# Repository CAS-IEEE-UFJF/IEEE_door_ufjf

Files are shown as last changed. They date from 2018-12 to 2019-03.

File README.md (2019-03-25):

<!-- ![](https://img.shields.io/badge/build-passing-rgb(76%2C198%2C31).svg) -->

| Projeto | estado| Observação |
| --- | ----- | --- |
| Leitura e separação entre carterinhas cadastradas e não cadastradas | | -- |
| Modo reunião |  | -- |
| Upload Firebase |  | Problemas na internet do ramo |
| Page local | | -- |
| Page na internet |  | --|

[comment]: <https://img.shields.io/badge/build-unknown-lightgrey.svg>

### [Página online:](https://cas-ieee-ufjf.github.io/IEEE_door_ufjf/)
https://cas-ieee-ufjf.github.io/IEEE_door_ufjf/ é o mesmo site do QR code que está no ramo.

## [ 2º Versão](https://github.com/wesley-cantarino/IEEE_door_ufjf/tree/master/version2)
### Apresentação

O Ramo Estudantil IEEE devido ao seu grande número de membros, necessitava de um melhor controle de acesso ao seu domínio. Porém, as trancas convencionais demandam cópias de chave e não havia como saber quem entrou e em qual horário. A partir disso fizemos um levantamento de qual seria a melhor proposta para resolver o controle de acesso ao tempo que pudéssemos gerenciar as chaves. Em nosso levantamento descobrimos que as carteirinhas estudantis possuíam um dispositivo interno para identificação chamado de radiofrequência chamado RFID, elas por sua vez, são chaves únicas e podem ser obtidas através de leitura.

### Objetivo

O projeto Porta Tunada 2.0 consiste em um equipamento eficiente e de baixo custo para controlar a entrada e saída de pessoas na sala do Ramo Estudantil IEEE UFJF, estando restrito o acesso somente aos membros que tenham suas carteirinhas estudantis cadastradas. Nessa 2º versão fomentamos a equipe o uso do nodeMCU (ESP8266) e para desenvolver a capacidade de programação em IOT.

### Descrição do funcionamento:

Quando uma pessoa aproxima sua carteirinha do equipamento, o RFID - RC522 é o sensor que faz a leitura da tag da carteirinha aproximada. O ESP8266 recebe essa informação e permite que o motor abra a porta, somente se, a mesma for reconhecida. E, então, o LED verde acende e o motor é acionado abrindo a porta. Caso contrário, o buzzer emite um som e o LED vermelho acende. A fonte é utilizada para alimentar o circuito, a ponte H controla o movimento do motor e os jumpers fazem a ligação entre os componentes.

### Componentes utilizados:

* Fonte de 12V;
* Fonte 5V;
* Microcontrolador ESP8266;
* Sensor RFDI - RC522;
* Ponte H - l290n;
* Motor DC;
* Dois LED’s (um vermelho e um verde);
* Buzzer;
* Jumpers.

<hr>

* #### foto:
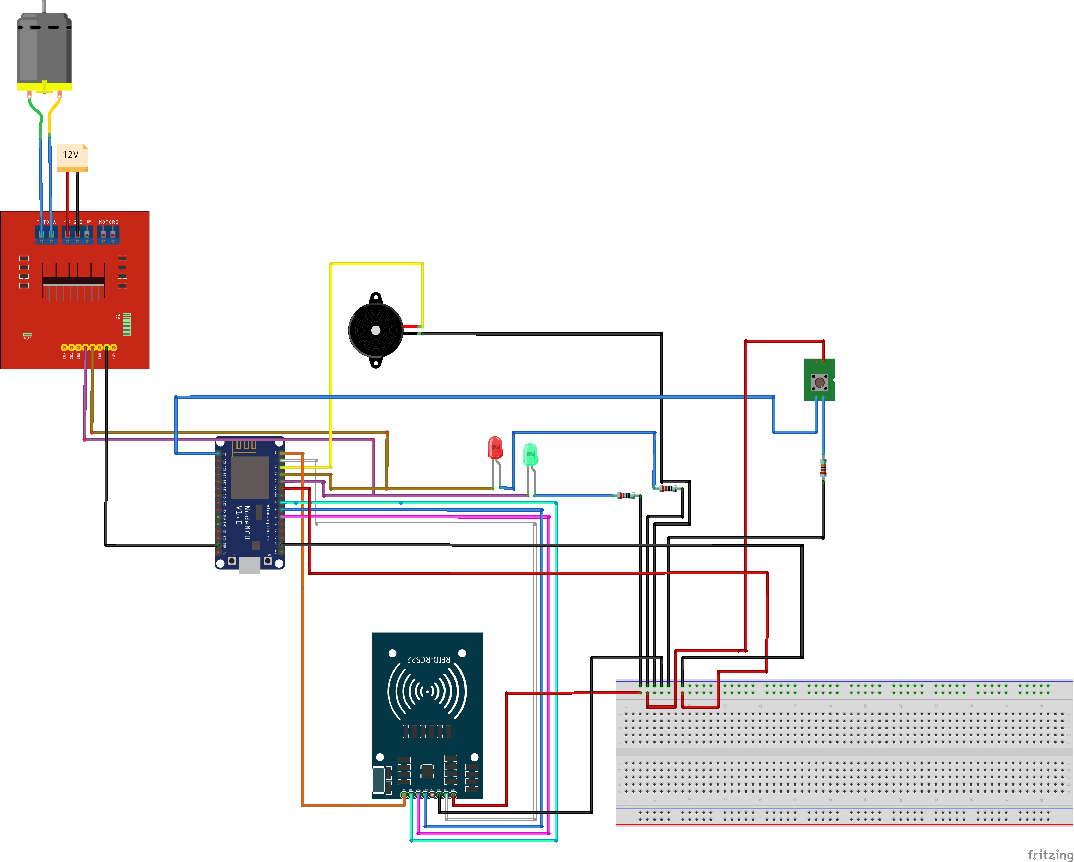
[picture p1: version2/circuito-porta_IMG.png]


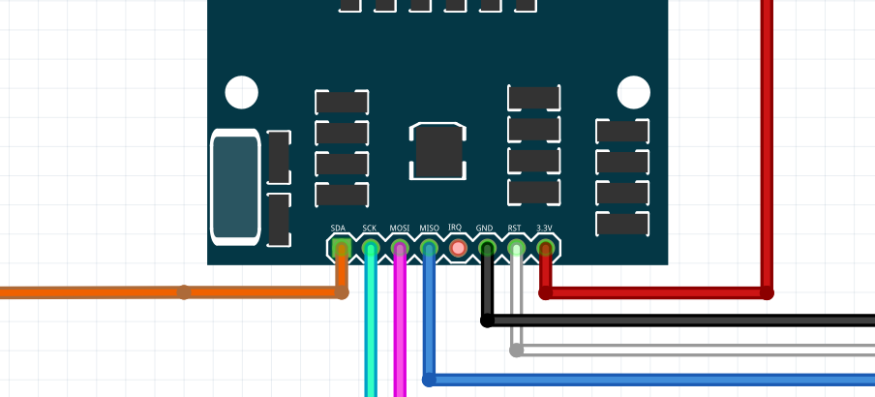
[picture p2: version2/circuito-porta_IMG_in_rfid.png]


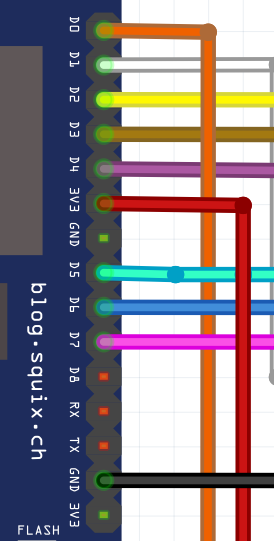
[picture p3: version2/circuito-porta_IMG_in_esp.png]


* #### flowchart:

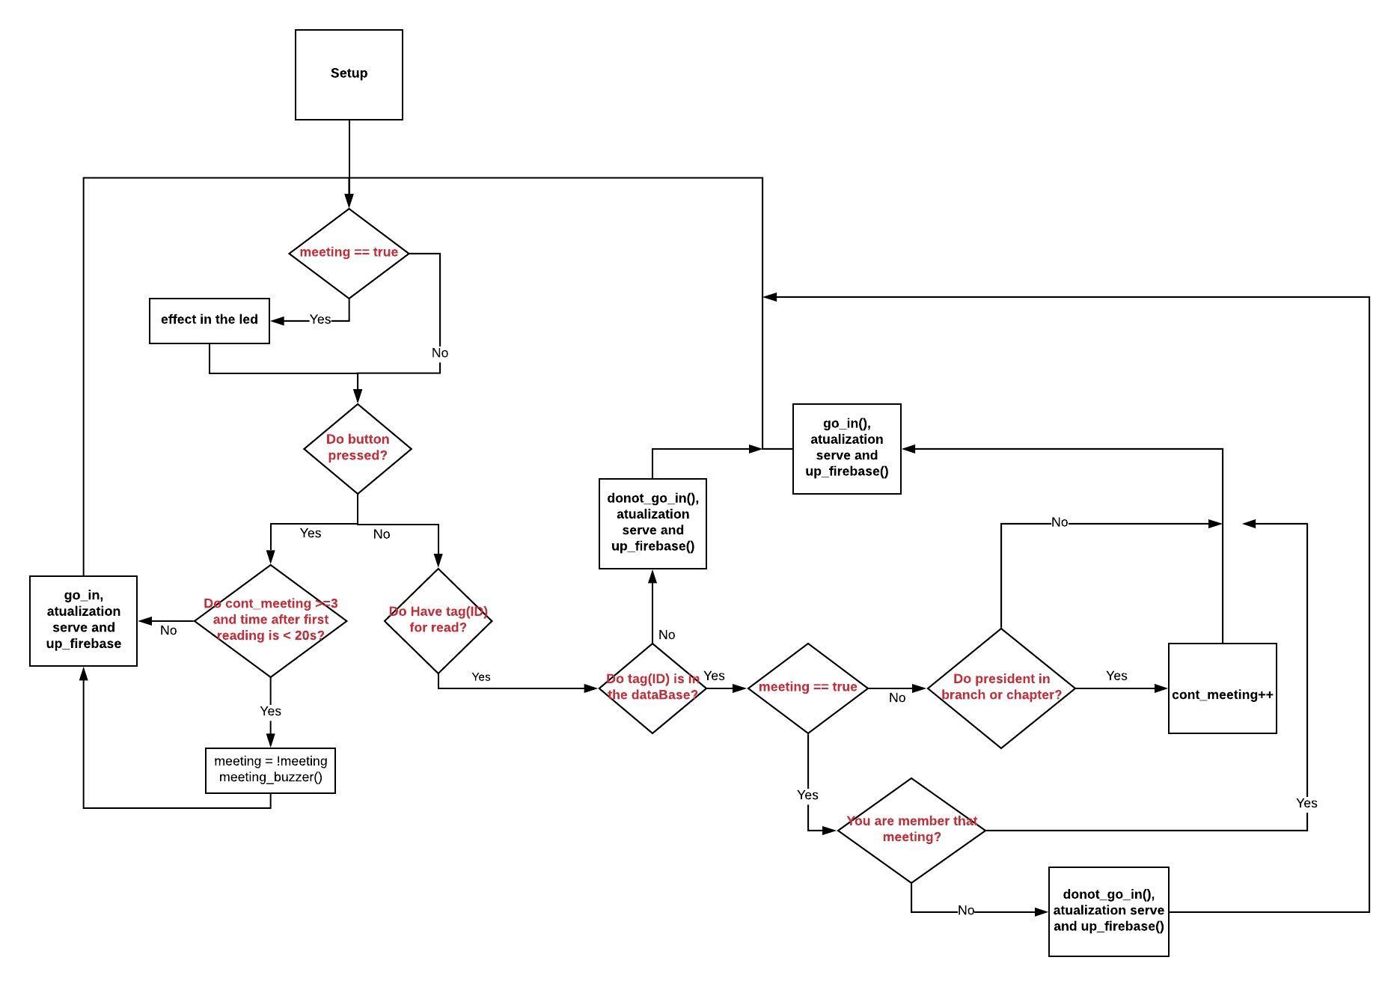
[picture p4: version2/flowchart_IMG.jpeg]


### Oque é modo reunião?

Modo reunião é uma função que permite selecionar quem vai ter acesso ao ramo em determinado momento. Somente o presidente do capítulo ou cargo algum cargo da gestão pode iniciar o modo reunião. 

Exemplo o presidente da eletrônica iniciou o modo reunião. Os led's vão começar a piscar (indicativo que está no modo reunião) e terá efeito sonoro para indicar que estrou no modo reunião. Depois disso, somente membros da eletrônica conseguirão entrar e qualquer outro membro ou presidente terá acesso negado.

Para ativar o modo reunião o presidente terá que passar sua carteirinha 3 ou mais vezes e pressionar o botão interno. Tudo isso em menos de 25s (da para fazer tudo isso em 9s).

Se um presidente passa sua carteirinha, mas não ativa o modo reunião e em menos de 25s vem outro presidente e passa sua carteirinha tentando ativar o modo reunião. Então, esse presidente terá que aguardar o contador interno zerar. Isso leva entorno de 25s.

### Files

```
.
|--- item_adicionais
     |--- contador
          |--- contador.ino
          |--- esquematico_IMG.jpg
          |--- esquematico_fritzing.fzz
          |--- sn74hc595-datasheet.pdf
          |--- video_01.mp4
          |--- video_02.mp4
     |--- matriz_numerica
          |--- library
               |--- keypad.zip
          |--- ZRX_543.jpg
          |--- matriz_numerica.ino
     |--- readme.md
|--- version1
     |--- main.ino
|--- version2
     |--- CODE
          |--- library
               |--- firebase-arduino-master.rar
               |--- rfid-master.rar
          |--- testes
               |--- test_RFID_only.ino
               |--- test_simples.ino
               |--- textHTML_exemple.html
          |--- main.ino
     |--- circuito-porta.fzz
     |--- circuito-porta_IMG.png
     |--- circuito-porta_IMG_in_esp.png
     |--- circuito-porta_IMG_in_rfid.png
     |--- componentes.txt
     |--- flowchart_IMG.jpeg
|--- .gitignore
|--- README.md
|--- this_is_nodeMCU.pdf
```

## [ 1º Versão](https://github.com/wesley-cantarino/IEEE_door_ufjf/tree/master/version1)
Objetivo da 1º versão é apresentar para a equipe o Arduino e desenvolver a capacidade de programação.

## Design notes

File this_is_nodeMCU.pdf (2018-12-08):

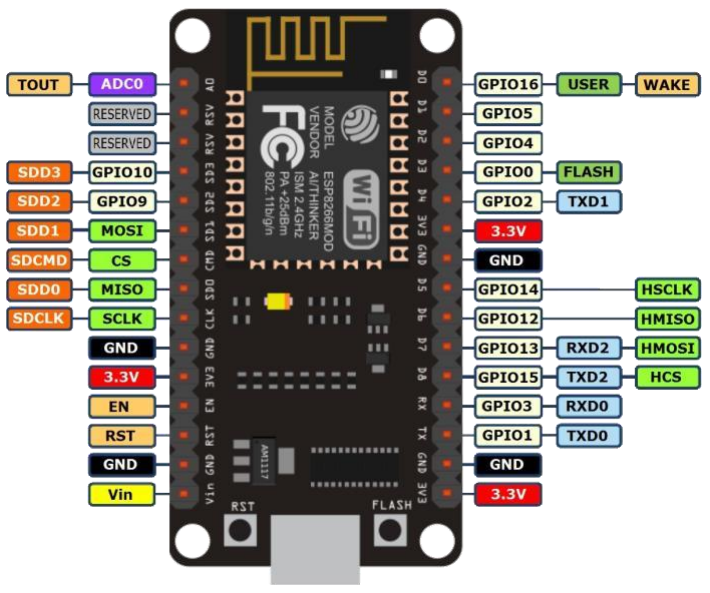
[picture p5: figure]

- VIN – Esse é o pino de alimentação externa ( recomendo 5,0V / 1A). Pode usar até 9V, mas o regulador da placa deverá esquentar. Não use-o se estiver usando a USB.
- GND– Esse é o terra da placa. Não se esqueça de conectá-lo ao terra de outros dispositivos.
- RST – Reset do módulo ESP-12. Nível LOW(0V) dá um reboot na placa.
- EN – (Enable) ativa o módulo ESP-12 quando o nível for HIGH(3,3V).
- 3.3V – saída do regulador interno 3,3V – Para alimentar outro dispositivo, não use mais do que 500 mA de corrente.
- CLK – interface SPI (clock) – pino SCLK (GPIO_6)

- SD0 – interface SPI (master in serial out) – pino MISO (GPIO_7)
- CMD – interface SPI (chip select) – pino CS (GPIO_11)
- SD1 – interface SPI (master out serial in) – pino MOSI (GPIO_8)
- SD2 – pino GPIO_9 pode ser usado também para comunicação com SD Card (SDD2)
- SD3 – pino GIPO_10 – pode ser usado também para comunicação com SD Card (SDD3)
- RSV – reservado (não use).
- ADC0– pino de entrada do conversor analógico digital ADC de 10 bits. Tensão máxima de 1,1V (variação do valor digital – 0 a 1024).

D0 – pino GIPO_16 pode ser usado para acordar (WAKE UP) o ESP8266 em modo sono profundo (Deep sleep mode).

D1 – pino GPIO_5 – entrada ou saída.

D2 – pino GIPO_4 – entrada ou saída.

D3 – pino GPIO_0 é usado também para controlar o upload do programa na memória Flash. Esta conectado no botão FLASH.

D4 – pino GPIO_2 – UART_TXD1 quando carregando o programa na memória FLASH

D5 – pino GPIO_14 pode ser usado em SPI de alta velocidade (HSPI-SCLK)

D6 – pino GPIO_12 pode ser usado em SPI de alta velocidade (HSPI-MISO)

D7 – pino GPIO_13 pode ser usado em SPI de alta velocidade (HSPI-MOSI) ou UART0_CTS.

D8 – pino GPIO_15 pode ser usado em SPI de alta velocidade (HSPI-CS) ou UART0_RTS.

RX – pino GPIO_3 – U0RXD quando carregando o programa na memória FLASH.

TX – pino GIPO_1 – U0TXD quando carregando o programa na memória FLASH.

GPIO
static const uint8_t D0 | = 16;
static const uint8_t D1 | = 5;
static const uint8_t D2 | = 4;
static const uint8_t D3 | = 0;
static const uint8_t D4 | = 2;
static const uint8_t D5 | = 14;
static const uint8_t D6 | = 12;
static const uint8_t D7 | = 13;
static const uint8_t D8 | = 15;
static const uint8_t D9 | = 3;
static const uint8_t D10 | = 1;

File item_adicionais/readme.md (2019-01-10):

### What's contador?

  Contador é um CI que permite realizar a escrita digital de até 8 portas usando apenas 3 portas do seu microcontrolador.

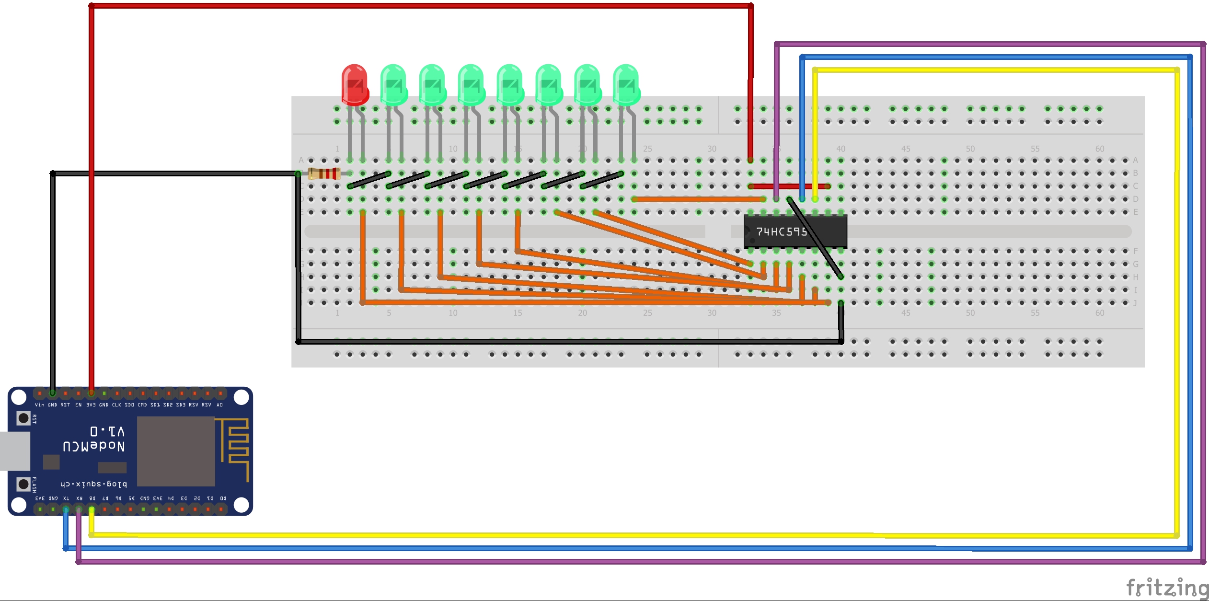
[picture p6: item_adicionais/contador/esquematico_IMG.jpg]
  

### What's matriz numérica?

  É uma tabela de 16 botões com números indo de 0 a F (hexadecimais).

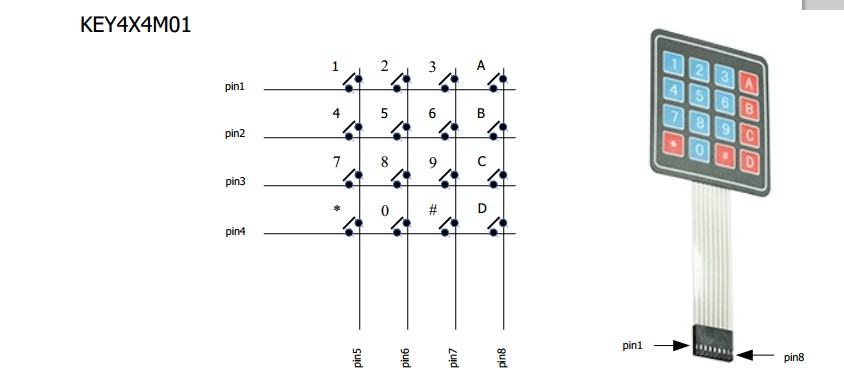
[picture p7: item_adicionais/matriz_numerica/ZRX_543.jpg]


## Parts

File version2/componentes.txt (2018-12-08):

Fonte 12V_____ R$ 15
       5V_____ R$ ??

ESP8266_______ R$ 35
RFID__________ R$ 15
Ponte H l290n_ R$ 18
Motor_________ R$ 20

LED (x2)____  
Buzzer______ 
jumper (xN)_

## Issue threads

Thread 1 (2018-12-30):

collapse RFID

wesley-cantarino, 2018-12-30:
_From @wesley-cantarino on December 18, 2018 23:47_

#### Apos certo tempo (indeterminado) o RFID para de responder

Lendo o readme da biblioteca descobri esses 4 tópicos:

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

_Copied from original issue: wesley-cantarino/IEEE_door_ufjf#1_

wesley-cantarino, 2019-01-06:
Quando tempo algum corpo entre ou próximo da tag e do rfid.

Exemplo o rfid em cima do notebook (metal).

O rfid NÂO faz leitura da tag. talvez, se colocar uma esponja atrás do rfid ajude.

wesley-cantarino, 2019-01-06:
07/01 vou soldar os pinos SPI  e vou adicionar essas linhas dentro da função loop

``` C++
rfid.PCD_Init();
rfid.PCD_SetAntennaGain(rfid.RxGain_max);
delay(500);
```

tomara que isto funcione

wesley-cantarino, 2019-01-08:
por enquanto está tudo tranquilo 😄

Closed 2019-03-07.

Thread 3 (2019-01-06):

Outros artigos :smile:

wesley-cantarino, 2019-01-06:
add pdf here

wesley-cantarino, 2019-01-06:
muito bom este PDF [rfidmifare.pdf](https://github.com/CAS-IEEE-UFJF/IEEE_door_ufjf/files/2730045/rfidmifare.pdf)

muito bom este site https://blogventor.wordpress.com/2017/04/14/how-does-rfid-communicate-with-arduino/

wesley-cantarino, 2019-01-10:
programação orientada a objeto com arduino

https://www.radishlogic.com/arduino/use-c-class-arduino-ide-without-creating-library/

https://www.geeksforgeeks.org/array-class-c/

wesley-cantarino, 2019-01-10:
http://people.cs.vt.edu/kafura/cs2704/arrays.html

wesley-cantarino, 2019-01-11:
```C++
const int c = 261;
const int d = 294;
const int e = 329;
const int f = 349;
const int g = 391;
const int gS = 415;
const int a = 440;
const int aS = 455;
const int b = 466;
const int cH = 523;
const int cSH = 554;
const int dH = 587;
const int dSH = 622;
const int eH = 659;
const int fH = 698;
const int fSH = 740;
const int gH = 784;
const int gSH = 830;
const int aH = 880;

#define buzzerPin D2
const int ledPin1 = 12;
const int ledPin2 = 13;

int counter = 0;

void setup()
{
  //Setup pin modes
  pinMode(buzzerPin, OUTPUT);
  pinMode(ledPin1, OUTPUT);
  pinMode(ledPin2, OUTPUT);
}

void loop()
{

  //Play first section
  firstSection();

  //Play second section
  secondSection();

  //Variant 1
  beep(f, 250);
  beep(gS, 500);
  beep(f, 350);
  beep(a, 125);
  beep(cH, 500);
  beep(a, 375);
  beep(cH, 125);
  beep(eH, 650);

  delay(500);

  //Repeat second section
  secondSection();

  //Variant 2
  beep(f, 250);
  beep(gS, 500);
  beep(f, 375);
  beep(cH, 125);
  beep(a, 500);
  beep(f, 375);
  beep(cH, 125);
  beep(a, 650);

  delay(650);
}

void beep(int note, int duration)
{
  //Play tone on buzzerPin
  tone(buzzerPin, note, duration);

  //Play different LED depending on value of 'counter'
  if(counter % 2 == 0)
  {
    digitalWrite(ledPin1, HIGH);
    delay(duration);
    digitalWrite(ledPin1, LOW);
  }else
  {
    digitalWrite(ledPin2, HIGH);
    delay(duration);
    digitalWrite(ledPin2, LOW);
  }

  //Stop tone on buzzerPin
  noTone(buzzerPin);

  delay(50);

  //Increment counter
  counter++;
}

void firstSection()
{
  beep(a, 500);
  beep(a, 500);
  beep(a, 500);
  beep(f, 350);
  beep(cH, 150);
  beep(a, 500);
  beep(f, 350);
  beep(cH, 150);
  beep(a, 650);

  delay(500);

  beep(eH, 500);
  beep(eH, 500);
  beep(eH, 500);
  beep(fH, 350);
  beep(cH, 150);
  beep(gS, 500);
  beep(f, 350);
  beep(cH, 150);
  beep(a, 650);

  delay(500);
}

void secondSection()
{
  beep(aH, 500);
  beep(a, 300);
  beep(a, 150);
  beep(aH, 500);
  beep(gSH, 325);
  beep(gH, 175);
  beep(fSH, 125);
  beep(fH, 125);
  beep(fSH, 250);

  delay(325);

  beep(aS, 250);
  beep(dSH, 500);
  beep(dH, 325);
  beep(cSH, 175);
  beep(cH, 125);
  beep(b, 125);
  beep(cH, 250);

  delay(350);
}
```

wesley-cantarino, 2019-01-23:
### Database as a Service with Firebase

https://www.youtube.com/watch?v=JrHT1iqSrAQ&list=PLRqwX-V7Uu6agS82Le9lLCBbeaW8inATT

wesley-cantarino, 2019-01-23:
### Working with data

https://www.youtube.com/watch?v=rJaXOFfwGVw&list=PLRqwX-V7Uu6a-SQiI4RtIwuOrLJGnel0r

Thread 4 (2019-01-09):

fotos

wesley-cantarino, 2019-01-09:
fotos do projeto e memes :D

wesley-cantarino, 2019-01-09:
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

wesley-cantarino, 2019-01-09:
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

wesley-cantarino, 2019-01-09:
[videos_ate_09_01_2019_que_eu_tenho.zip](https://github.com/CAS-IEEE-UFJF/IEEE_door_ufjf/files/2740444/videos_ate_09_01_2019_que_eu_tenho.zip)

wesley-cantarino, 2019-01-12:
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
[videos_11_01_2019.zip](https://github.com/CAS-IEEE-UFJF/IEEE_door_ufjf/files/2751540/videos_11_01_2019.zip)

wesley-cantarino, 2019-01-25:
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

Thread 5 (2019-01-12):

fazer som com buzzer

wesley-cantarino, 2019-01-12:

wesley-cantarino, 2019-01-12:
star wars

```C++
const int c = 261;
const int d = 294;
const int e = 329;
const int f = 349;
const int g = 391;
const int gS = 415;
const int a = 440;
const int aS = 455;
const int b = 466;
const int cH = 523;
const int cSH = 554;
const int dH = 587;
const int dSH = 622;
const int eH = 659;
const int fH = 698;
const int fSH = 740;
const int gH = 784;
const int gSH = 830;
const int aH = 880;

const int buzzerPin = 8;
const int ledPin1 = 12;
const int ledPin2 = 13;

int counter = 0;

void setup()
{
  //Setup pin modes
  pinMode(buzzerPin, OUTPUT);
  pinMode(ledPin1, OUTPUT);
  pinMode(ledPin2, OUTPUT);
}

void loop()
{

  //Play first section
  firstSection();

  //Play second section
  secondSection();

  //Variant 1
  beep(f, 250);
  beep(gS, 500);
  beep(f, 350);
  beep(a, 125);
  beep(cH, 500);
  beep(a, 375);
  beep(cH, 125);
  beep(eH, 650);

  delay(500);

  //Repeat second section
  secondSection();

  //Variant 2
  beep(f, 250);
  beep(gS, 500);
  beep(f, 375);
  beep(cH, 125);
  beep(a, 500);
  beep(f, 375);
  beep(cH, 125);
  beep(a, 650);

  delay(650);
}

void beep(int note, int duration)
{
  //Play tone on buzzerPin
  tone(buzzerPin, note, duration);

  //Play different LED depending on value of 'counter'
  if(counter % 2 == 0)
  {
    digitalWrite(ledPin1, HIGH);
    delay(duration);
    digitalWrite(ledPin1, LOW);
  }else
  {
    digitalWrite(ledPin2, HIGH);
    delay(duration);
    digitalWrite(ledPin2, LOW);
  }

  //Stop tone on buzzerPin
  noTone(buzzerPin);

  delay(50);

  //Increment counter
  counter++;
}

void firstSection()
{
  beep(a, 500);
  beep(a, 500);
  beep(a, 500);
  beep(f, 350);
  beep(cH, 150);
  beep(a, 500);
  beep(f, 350);
  beep(cH, 150);
  beep(a, 650);

  delay(500);

  beep(eH, 500);
  beep(eH, 500);
  beep(eH, 500);
  beep(fH, 350);
  beep(cH, 150);
  beep(gS, 500);
  beep(f, 350);
  beep(cH, 150);
  beep(a, 650);

  delay(500);
}

void secondSection()
{
  beep(aH, 500);
  beep(a, 300);
  beep(a, 150);
  beep(aH, 500);
  beep(gSH, 325);
  beep(gH, 175);
  beep(fSH, 125);
  beep(fH, 125);
  beep(fSH, 250);

  delay(325);

  beep(aS, 250);
  beep(dSH, 500);
  beep(dH, 325);
  beep(cSH, 175);
  beep(cH, 125);
  beep(b, 125);
  beep(cH, 250);

  delay(350);
}
```

wesley-cantarino, 2019-01-12:
donot_go_in

```C++
tone(BUZZER, 523);
  delay(180);
  noTone(BUZZER);

  tone(BUZZER, 294);
  delay(120);
  noTone(BUZZER);

  tone(BUZZER, 440);
  delay(110);
  noTone(BUZZER);

  tone(BUZZER, 349);
  delay(110);
  noTone(BUZZER);

  tone(BUZZER, 294);
  delay(100);
noTone(BUZZER);
```

wesley-cantarino, 2019-01-12:
go_in_DEV

```C++
 tone(BUZZER, 294);
  delay(100);
  noTone(BUZZER);

  tone(BUZZER, 349);
  delay(110);
  noTone(BUZZER);

  tone(BUZZER, 440);
  delay(110);
  noTone(BUZZER);

  tone(BUZZER, 294);
  delay(120);
  noTone(BUZZER);

  tone(BUZZER, 523);
  delay(180);
  noTone(BUZZER);

  delay(100);
  tone(BUZZER, 523);
  delay(180);
noTone(BUZZER);
```

wesley-cantarino, 2019-01-12:
go_in
```C++
tone(BUZZER, 294);
  delay(100);
  noTone(BUZZER);

  tone(BUZZER, 349);
  delay(110);
  noTone(BUZZER);

  tone(BUZZER, 440);
  delay(110);
  noTone(BUZZER);

  tone(BUZZER, 294);
  delay(120);
  noTone(BUZZER);

  tone(BUZZER, 523);
  delay(180);
noTone(BUZZER);
```

Closed 2019-03-07.

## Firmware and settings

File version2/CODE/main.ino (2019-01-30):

/*************************************************************************************************/
/* ÚLTIMA:     ATUALIZAÇÃO                                           UPLOAD nodeMCU              */
/*           30/01/2019 11:00                                       30/01/2019 12:00             */
/*                                                                                               */
/*     30/01/2019 11:00 - Ajuster na função main                                                 */
/*     27/01/2019 12:00 - Novos comentários                                                      */
/*     26/01/2019 14:21 - Correção do Modo reunião, print_DEV enviando t == true e f == false,   */
/*set tempo máximo de reunião como 1h20 == 80min.                                                */
/*     25/01/2019 17:00 - Retornar para versão de segunda feira (21/01/2019) pois ela esta       */
/*estável.                                                                                       */
/*************************************************************************************************/

/*************************************************************************************************/
/*                                  NOTAS sobre modo reunião                                     */
/* Ex: Eu (wesley) passo minha minha carteirinha 2 vezes seguidas (exemplo) mas eu não ativo o   */
/*modo reunião (eu não quero ativar modo reunião) e digamos que o próximo  pessoa seja um        */
/*presidente e queira ativar modo reunião. Ele NÃO vai conseguir pois o contador está vinculada a*/
/*minha carteirinha somente após 25s depois da minha primeira leitura que ele vai conseguir      */
/*ativar o modo reunião.                                                                         */
/*                                                                                               */
/*                                        BUTTON                                                 */
/* O tempo de resposta do botão NÂO está instantâneo!!!!!! para resolver isso, teríamos que usar */
/*interrupção por hardware e eliminar os delay(). É melhor educar a galera como sendo um botão de*/
/*pressão                                                                                        */
/*************************************************************************************************/

/*****library_str******/ //str == start
#include <Arduino.h> //tem que importar pois estou usando platformIO

//na real mesmo tem biblioteca aqui que não esta sendo usada mas deixa assim mesmo
#include <ESP8266WiFi.h>
#include <WiFiClient.h>
#include <ESP8266WebServer.h>
#include <ESP8266mDNS.h>
#include <DNSServer.h>
#include <ESP8266HTTPClient.h>

#include <FirebaseArduino.h> //o biblioteca problematica. só de importar já da erro

#include <SPI.h> //protocol SPI
#include <MFRC522.h> //RFID
/*****library_end******/

/************************/
#define RST_PIN 5  //GPIO05 ou D1 no nodeMCU, Reset no RFID
#define SS_PIN 16  //GPIO15 ou D0 no nodeMCU, SDA no RFID
                   //GPIO12 ou D6 no nodeMCU, MISO no RFID
                   //GPIO13 ou D7 no nodeMCU, MOSI no RFID
                   //GPIO14 ou D5 no nodeMCU, SCK no RFID

MFRC522 mfrc522(SS_PIN, RST_PIN);

/*os pinos de controle do motor também estão ligados aqui(ou seja a ponte H e os LED vermelho e verde tem na verdade o
mesmo pino) pois não tem 2 pinos sobrando só para eles*/

#define RED_LED D4
#define GRE_LED D3

#define BUZZER  D2

const int button = A0;
/************************/

/************************/
/*
const char* ssid = "";      //nome da rede
const char* password = "";  //senha da rede
*/
const char* ssid = "";      //nome da rede
const char* password = "";  //senha da rede
/*
const char* ssid = "";      //nome da rede
const char* password = "";  //senha da rede
*/

#define FIREBASE_HOST ""   //autenticação no firebase
#define FIREBASE_AUTH ""

ESP8266WebServer server(80);  //porta 80 é padrão para entrada e saída de dados
/************************/

/************************/
class membro_class
{
  public:
    String UID, nome;
    boolean dev = false; //grupos em que a pessoa está. Por padrão vem setado como falso

    bool coisas [27] = {false};
    /*Conseguem iniciar modo reunião
       0   false, //CAS: presidente
       1   false, //RAS: presidente
       2   false, //PES: presidente
       3   false, //IAS: presidente
       4   false, //SIGHT: presidente
       5   false, //WIE: presidente
       6   false, //SPEAK: presidente
       7   false, //QUALIDADE: presidente
       8   false, //MKT: presidente
       9   false, //EVENTOS: presidente
       10  false, //TI: presidente
       11  false, //CONSELHO: presidente
       12  false, //GP: presidente
       13  false, //PROFESSOR: presidente

	  NÃO conseguem iniciar modo reunião
       14  false, //CAS: membro
       15  false, //RAS: membro
       16  false, //PES: membro
       17  false, //IAS: membro
       18  false, //SIGHT: membro
       19  false, //WIE: membro
       20  false, //SPEAK: membro
       21  false, //QUALIDADE: membro
       22  false, //MKT: membro
       23  false, //EVENTOS: membro
       24  false, //TI: membro
       25  false, //CONSELHO: membro
       26  false, //GP: membro

       27 no total
    */

    membro_class(String UID_aux, String nome_aux)
    {
      UID = UID_aux;
      nome = nome_aux;
    }
};

int tam_DB = 25; //tam db //<---------- alterar aqui!!!!!!!
membro_class membro[] =
{
    
};

boolean print_DEV = false; //imprimir variáveis na porta USB

String tag_now = "";  //tag lida recentimente
int tag_db = 0;

//histórico no servidor local
String tag_backup[32] = ""; //código da tag
int tag_db_backup[32];      //posição da tag
int tag_y_db_backup[32];    //está no db?

boolean meeting = false; //modo reunião
int cont_meeting = 0; //contador para reunião

int quem_ativou = 200;

String tag_time = ""; //tag quando o contador (cont_meeting) é 1
double time_now = 0;
double time_aux = 0;
double time_max = 0;
//tem var aqui que podem se descartadas... mas... code 100% otimizado, não é prioridade.

void oque_a_pessoa_faz ()
{ //se a pessoa é desenvolvedor...
  //encontrar a pessoa e colocar verdadeiro(true) nas coisas que ela faz


}
/************************/

/*******server_str*******/
void handleRoot ()
{//html mega complexo...hahaha
  String textHTML;

  textHTML += "<!DOCTYPE HTML>";
  textHTML += "<html>";
    textHTML += "<head>";
      textHTML += " <meta http-equiv='refresh' content='3'>";
      textHTML += "<meta name'viewport' content='width=device-width, initial-scale=1.0'>";
      textHTML += "<title>ESP8266 Server</title>";
      textHTML += "<style>";
        textHTML += "body{background-color: #efefef;}";
      textHTML += "</style>";
    textHTML += "</head>";

    textHTML += "<body>";
      textHTML += "<center>";
      textHTML += "<h1>TAG</h1>";

      /************************/
      for(int i = 0; i < 32; i++)
      {
        textHTML += tag_backup[i]; //UID
        textHTML += ", ";

        if(tag_y_db_backup[i] == 1)
        {
        textHTML += membro[tag_db_backup[i]].nome;
        textHTML += "<br>";
        }
        else
        {
          textHTML += "unknown<br>";
        }
      }
      /************************/

    textHTML += "</body>";
  textHTML += "</html>";

  server.send(200, "text/html", textHTML);
}

void handleNotFound ()
{
  String message = "File Not Found\n\n";
  message += "URI: ";
  message += server.uri();
  message += "\nMethod: ";
  message += (server.method() == HTTP_GET)?"GET":"POST";
  message += "\nArguments: ";
  message += server.args();
  message += "\n";
  for (uint8_t i=0; i<server.args(); i++)
  {
    message += " " + server.argName(i) + ": " + server.arg(i) + "\n";
  }
  server.send(404, "text/plain", message);
}
/*******server_end*******/

void go_in ()
{ //efeito normal de entrada (go_in)
  if(print_DEV)
    Serial.println("go_in V");

  digitalWrite(GRE_LED, HIGH);
  digitalWrite(RED_LED, LOW);
  /*************************/

  tone(BUZZER, 294);
  delay(100);
  noTone(BUZZER);

  tone(BUZZER, 349);
  delay(110);
  noTone(BUZZER);

  tone(BUZZER, 440);
  delay(110);
  noTone(BUZZER);

  tone(BUZZER, 294);
  delay(120);
  noTone(BUZZER);

  tone(BUZZER, 523);
  delay(180);
  noTone(BUZZER);

  /*************************/
  delay(500); //delay here
  digitalWrite(GRE_LED, LOW);
  digitalWrite(RED_LED, LOW);

  delay(50);
  digitalWrite(GRE_LED, LOW);
  digitalWrite(RED_LED, HIGH);
  delay(100);
  digitalWrite(GRE_LED, LOW);
  digitalWrite(RED_LED, LOW);
}

void go_in_DEV ()
{ //efeito diferenciado de entrada (go_in_DEV) para developer
  if(print_DEV)
    Serial.println("go_in_DEV V");

  digitalWrite(GRE_LED, HIGH);
  digitalWrite(RED_LED, LOW);
  /*************************/

  tone(BUZZER, 294);
  delay(100);
  noTone(BUZZER);

  tone(BUZZER, 349);
  delay(110);
  noTone(BUZZER);

  tone(BUZZER, 440);
  delay(110);
  noTone(BUZZER);

  tone(BUZZER, 294);
  delay(120);
  noTone(BUZZER);

  tone(BUZZER, 523);
  delay(180);
  noTone(BUZZER);

  delay(100);
  tone(BUZZER, 523);
  delay(180);
  noTone(BUZZER);

  /*************************/
  delay(500); //delay here
  digitalWrite(GRE_LED, LOW);
  digitalWrite(RED_LED, LOW);

  digitalWrite(GRE_LED, LOW);
  digitalWrite(RED_LED, HIGH);
  delay(100);
  digitalWrite(GRE_LED, LOW);
  digitalWrite(RED_LED, LOW);

  if(print_DEV)
    Serial.println("developer");
}


/******************************/
//minha música de star wars hehe
const int c = 261;
const int d = 294;
const int e = 329;
const int f = 349;
const int g = 391;
const int gS = 415;
const int a = 440;
const int aS = 455;
const int b = 466;
const int cH = 523;
const int cSH = 554;
const int dH = 587;
const int dSH = 622;
const int eH = 659;
const int fH = 698;
const int fSH = 740;
const int gH = 784;
const int gSH = 830;
const int aH = 880;

int counter = 0;

void beep(int note, int duration)
{
  //Play tone on buzzerPin
  tone(BUZZER, note);
  delay(duration);

  //Stop tone on buzzerPin
  noTone(BUZZER);

  delay(50);

  //Increment counter
  counter++;
}

void firstSection()
{
  beep(a, 500);
  beep(a, 500);
  beep(a, 500);
  beep(f, 350);
  beep(cH, 150);
  beep(a, 500);
  beep(f, 350);
  beep(cH, 150);
  beep(a, 650);

  /*
  delay(500);

  beep(eH, 500);
  beep(eH, 500);
  beep(eH, 500);
  beep(fH, 350);
  beep(cH, 150);
  beep(gS, 500);
  beep(f, 350);
  beep(cH, 150);
  beep(a, 650);

  delay(500);
  */
}

void secondSection()
{
  beep(aH, 500);
  beep(a, 300);
  beep(a, 150);
  beep(aH, 500);
  beep(gSH, 325);
  beep(gH, 175);
  beep(fSH, 125);
  beep(fH, 125);
  beep(fSH, 250);

  delay(325);

  beep(aS, 250);
  beep(dSH, 500);
  beep(dH, 325);
  beep(cSH, 175);
  beep(cH, 125);
  beep(b, 125);
  beep(cH, 250);

  delay(350);
}

void go_in_DEV_star_wars ()
{
  if(print_DEV)
    Serial.println("go_in_DEV_star_wars V");

  digitalWrite(GRE_LED, HIGH);
  digitalWrite(RED_LED, LOW);
  /*************************/

  //Play first section
  firstSection();

  //Play second section
  //secondSection();

  /*************************/
  digitalWrite(GRE_LED, LOW);
  digitalWrite(RED_LED, LOW);

  digitalWrite(GRE_LED, LOW);
  digitalWrite(RED_LED, HIGH);
  delay(100);
  digitalWrite(GRE_LED, LOW);
  digitalWrite(RED_LED, LOW);

  if(print_DEV)
    Serial.println("developer");
}
/******************************/

void donot_go_in ()
{ //tag nao cadastrada
  if(print_DEV)
    Serial.println("donot_go_in V");

  digitalWrite(RED_LED, HIGH);

  tone(BUZZER, 523);
  delay(180);
  noTone(BUZZER);

  tone(BUZZER, 294);
  delay(120);
  noTone(BUZZER);

  tone(BUZZER, 440);
  delay(110);
  noTone(BUZZER);

  tone(BUZZER, 349);
  delay(110);
  noTone(BUZZER);

  tone(BUZZER, 294);
  delay(100);
  noTone(BUZZER);

  digitalWrite(RED_LED, LOW);
}

void meeting_led ()
{ //piscar led vermelho para indicar que está em reunião
  digitalWrite(RED_LED, HIGH);
  digitalWrite(GRE_LED, HIGH);
  delay(200);
  digitalWrite(RED_LED, LOW);
  digitalWrite(GRE_LED, LOW);
  delay(100);
}

void meeting_buzzer ()
{
  tone(BUZZER, 294);
  delay(120);
  noTone(BUZZER);

  tone(BUZZER, 440);
  delay(110);
  noTone(BUZZER);
}

void up_firebase (String tag, boolean go_db)
{ //enviar as tag para firebase
  //desativado pois o roteador próprio do ramo não está conectando a internet
  /*
  if(print_DEV)
    Serial.println("-------firebase str-----------");

  if(go_db)
    Firebase.pushString("tag_read", tag + ", "); //+ name); falta o nome da pessoa
  else
    Firebase.pushString("tag_read", tag + ", " + "unknown");

  if (Firebase.failed())
  {
    if(print_DEV)
    {
      Serial.print("setting /number failed:");
      Serial.println(Firebase.error());
    }
  }

  if(print_DEV)
  {
    Serial.print("firebase: tag now: ");
    Serial.println(tag);
    Serial.println("--------firebase end----------");
  }*/
}

void function_main_meeting ()
{
  boolean go = false; //var aux para seber se a tag esta no db

  if(print_DEV)
    Serial.println("modo reuniao");

  for (int ddb = 0; ddb < tam_DB; ddb++)
  {//varrer db
    if (membro[ddb].UID == tag_now)
    {//se tiver no db
      if(print_DEV)
        Serial.println("Yes db");

        int va = quem_ativou - 14;
        if (membro[ddb].coisas[va])
        {//se for presidente então cont_meeting = cont_meeting + 1
          if(print_DEV)
          {
            Serial.print("presidente: ");
            Serial.println(va);
          }

          if(tag_time == tag_now)
          {
            cont_meeting += 1;

            if(!go)
              go_in();

            go = true;

            if(cont_meeting > 2)
              quem_ativou = va + 14;

            if(print_DEV)
            {
              Serial.print("cont_meeting += 1 --->");
              Serial.println(cont_meeting);
            }
          }

          if(cont_meeting == 0)
          {
            cont_meeting += 1;

            if(!go)
              go_in();

            go = true;
          }

          if(cont_meeting == 1)
          {
            time_now = millis();
            tag_time = tag_now;
          }

          if(print_DEV)
          {
            Serial.print(" va: ");
            Serial.println(va);
          }
        }

      if(!go)
      {
        if (membro[ddb].coisas[quem_ativou])
        {
          if(print_DEV)
          {
            Serial.print("ddb: ");
            Serial.println(ddb);
            Serial.println("-----");

            Serial.print("quem_ativou: ");
            Serial.println(quem_ativou);
          }
          if(!go)
            go_in();

          go = true;
        }
      }
      /*************/
    }
  }

  if(go == false)
  {
    donot_go_in();
  }
  else
  {
    go = false;
  }
}

void function_main_normal ()
{
  boolean go = false; //var aux para seber se a tag esta no db

  for(int i = 0; i < tam_DB; i++)
  {
    if (membro[i].UID == tag_now)
    {
      if(print_DEV)
        Serial.println("Yes db");

      //responsável por preparar o modo reunião
      for(int va = 0; va < 14; va++)
      {//varrer todos os presidentes
        if (membro[i].coisas[va])
        {//se for presidente então cont_meeting = cont_meeting + 1
          if(print_DEV)
          {
            Serial.print("presidente: ");
            Serial.println(va);
          }

          if(tag_time == tag_now)
          {
            cont_meeting += 1;

            if(cont_meeting > 2)
              quem_ativou = va + 14;

            if(print_DEV)
            {
              Serial.print("cont_meeting += 1 --->");
              Serial.println(cont_meeting);
            }
          }

          if(cont_meeting == 0)
          {
            cont_meeting += 1;

            time_now = millis();
            tag_time = tag_now;
          }

          if(print_DEV)
          {
            Serial.print(" va: ");
            Serial.println(va);
          }
        }
      }

      if (membro[i].dev) //eh developer
      {
        if ((membro[i].UID == "FD 3C 50 C5") || //eu quero que minha entrada seja triunfal
            (membro[i].UID == "51 4F E2 08"))
        {
          go_in_DEV_star_wars();
        }
        else
          go_in_DEV();
      }
      else
        go_in();


      tag_db_backup[0] = i;
      go = true;
      tag_y_db_backup[0] = 1;
    }
  }

  if (!go)
  {
    donot_go_in();
    if(print_DEV)
      Serial.println("No db");

    tag_y_db_backup[0] = 0;
  }

  up_firebase(tag_now, go); //envia a tag para firebase
  go = !go;
}

void function_main ()
{
  /*
    * Essa é a função principal pois é daqui que vai ser definido oque fazer com a tag lida
    * Verifica se esta no modo reunião.
    * Verifica se a tag esta no banco de dados. se sim, chama a função go_in ou go_in_DEV se for tag especial(developer)
  */

  for(int i = 31; i > 0; i--)
  {
    tag_backup [i] = tag_backup [i - 1];
    tag_db_backup [i] = tag_db_backup [i - 1];
    tag_y_db_backup [i] = tag_y_db_backup [i - 1];
  }

  tag_backup[0] = tag_now;

  if(print_DEV)
    Serial.println(tag_now);

  if(meeting)
  {
    function_main_meeting();
  }
  else
  {
    function_main_normal();
  }
}

void function_RFID ()
{
  /*essa função faz leitura do RFID*/
  //é confuso mas funciona

  // Procura por cartao RFID
  if ( ! mfrc522.PICC_IsNewCardPresent())
    return;

  // Seleciona o cartao RFID
  if ( ! mfrc522.PICC_ReadCardSerial())
    return;

  //Mostra UID na serial
  //Serial.print("UID da tag :");
  String conteudo= "";
  for (byte i = 0; i < mfrc522.uid.size; i++)
  {
    conteudo.concat(String(mfrc522.uid.uidByte[i] < 0x10 ? " 0" : " "));
    conteudo.concat(String(mfrc522.uid.uidByte[i], HEX));
  }
  conteudo.toUpperCase();

  if (conteudo.substring(1) == "01 D1 FC 52" || "03 1C A0 F6")
  { //não sei o motivo de ser entre esses dois valores
    tag_now = conteudo.substring(1);

    function_main();
  }
}

void setup ()
{
  oque_a_pessoa_faz();

  /************************/
  pinMode(GRE_LED, OUTPUT);
  pinMode(RED_LED, OUTPUT);
  pinMode(BUZZER, OUTPUT);

  SPI.begin();          // Inicia  SPI bus
  mfrc522.PCD_Init();   // Inicia MFRC522*/
  /************************/

  /************************/
  Serial.begin(115200);
  WiFi.mode(WIFI_STA);
  WiFi.begin(ssid, password);
  if(print_DEV)
    Serial.println("");

  // Wait for connection
  if (WiFi.status() != WL_CONNECTED)
  { //original era while mas if tbm funciona
    delay(200);
    Serial.print(".");
  }

  if(print_DEV)
  {
    Serial.println("");
    Serial.print("Connected to ");
    Serial.println(ssid);
    Serial.print("IP address: ");
    Serial.println(WiFi.localIP());
  }

  if (MDNS.begin("esp8266"))
  {
    if(print_DEV)
      Serial.println("MDNS responder started");
  }

  server.on("/", handleRoot);

  server.on("/inline", []()
  {
    server.send(200, "text/plain", "this works as well");
  });

  server.onNotFound(handleNotFound);

  server.begin();
  if(print_DEV)
    Serial.println("HTTP server started");

  Firebase.begin(FIREBASE_HOST, FIREBASE_AUTH);
  /************************/
}

void loop ()
{
  mfrc522.PCD_Init();
  mfrc522.PCD_SetAntennaGain(mfrc522.RxGain_max);
  delay(25);

  if (analogRead(button) >= 1000)
  { //se o botão foi presionado. Isso significa que tem gente dentro do ramo querendo sair
    go_in(); //abrir a porta

    for(int i = 31; i > 0; i--)
    { //atualizar db
      tag_backup [i] = tag_backup [i - 1];
      tag_db_backup [i] = tag_db_backup [i - 1];
      tag_y_db_backup [i] = tag_y_db_backup [i - 1];
    }

    tag_backup [0] = "button pressed";
    tag_y_db_backup [0] = 0;

    if(print_DEV)
      Serial.println("button pressed");
    up_firebase("button pressed", false);

    /*********/
    if(print_DEV)
    {
      Serial.print("IP address: "); //mostrar qual o IP do esp na porta serial. para developer
      Serial.println(WiFi.localIP());
    }

    if((cont_meeting > 2) && (time_aux - time_now <= 25000)) //25segundos
    {
      meeting = !meeting;
      meeting_buzzer();  //efeito sonoro para indicar que entrou (ou saiu) do modo reunião
      cont_meeting = 0;

      if(meeting)
        time_max = millis();
    }

    if(print_DEV)
    {
      Serial.print("cont_meeting:");
      Serial.print(cont_meeting);
      Serial.print("  meeting:");
      Serial.println(meeting);
    }
  }

  else
  {
    function_RFID();
    server.handleClient();
  }


  if(meeting)
  {
    meeting_led();

    if(millis() - time_max > 4800000) // (80min)*[60s/1min]*[1000ms/s] = 4 800 000ms
      meeting = !meeting;
  }

  time_aux = millis();

  if(time_aux - time_now > 25000) //25s
  {
    cont_meeting = 0;
  }

  if(print_DEV)
  {
    Serial.print("meeting: ");
    Serial.println(meeting);

    Serial.print("cont_meeting: ");
    Serial.println(cont_meeting);

    Serial.print("quem_ativou: ");
    Serial.println(quem_ativou);

    Serial.print("time_now: ");
    Serial.println(time_now);

    Serial.print("time_aux: ");
    Serial.println(time_aux);

    Serial.print("tag_time: ");
    Serial.println(tag_time);

    Serial.print("time_max: ");
    Serial.println(time_max);

    Serial.println("------------------------------");

    delay(500);
  }

  while(Serial.available() > 0)
  {
    char r = Serial.read();

    if((r == 'T') || (r == 't'))
      print_DEV = true;
    else if((r == 'F') || (r == 'f'))
      print_DEV = false;
  }
}

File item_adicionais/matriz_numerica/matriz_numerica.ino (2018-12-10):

//fazendo leitura na marra
//ainda em desenvolvimento

/*parece que algumas teclas agarram.
  obs: o problema foi corrigido colocando resistor e ground nos pinos de leitura. equivalente a button push_down*/

#include <Arduino.h>

//olhando os pinos da matriz de frente. O primeiro pino da esquerda é o 1 o segundo é o 2 e assim por diante ate o oitavo pino

const int l1 = 0;  //D3 in nodeMCU and 1 in keypad
const int l2 = 12; //D6 in nodeMCU and 2 in keypad
const int l3 = 14; //D5 in nodeMCU and 3 in keypad
const int l4 = 2;  //D4 in nodeMCU and 4 in keypad

                   //colocar ground (com resistor)
const int c1 = 16; //D0 in nodeMCU and 5 in keypad
const int c2 = 4;  //D2 in nodeMCU and 6 in keypad
const int c3 = 5;  //D1 in nodeMCU and 7 in keypad
const int c4 = 13; //D7 in nodeMCU and 8 in keypad

void desligar (){
  digitalWrite(l1, LOW);
  digitalWrite(l2, LOW);
  digitalWrite(l3, LOW);
  digitalWrite(l4, LOW);
}

void pesquisar (int l){
  if (digitalRead(c1) == HIGH){
    if(l == 1)
      Serial.print("1  ");
    if(l == 2)
      Serial.print("4  ");
    if(l == 3)
      Serial.print("7  ");
    if(l == 4)
      Serial.print("*  ");

    while(digitalRead(c1) == HIGH){
      //travar code
    }
  }

  if (digitalRead(c2) == HIGH){
    if(l == 1)
      Serial.print("2  ");
    if(l == 2)
      Serial.print("5  ");
    if(l == 3)
      Serial.print("8  ");
    if(l == 4)
      Serial.print("0  ");

    while(digitalRead(c2) == HIGH){
      //travar code
    }
  }

  if (digitalRead(c3) == HIGH){
    if(l == 1)
      Serial.print("3  ");
    if(l == 2)
      Serial.print("6  ");
    if(l == 3)
      Serial.print("9  ");
    if(l == 4)
      Serial.print("#  ");

    while(digitalRead(c3) == HIGH){
      //travar code
    }
  }

  if (digitalRead(c4) == HIGH){
    if(l == 1)
      Serial.print("A  ");
    if(l == 2)
      Serial.print("B  ");
    if(l == 3)
      Serial.print("C  ");
    if(l == 4)
      Serial.print("D  ");

    while(digitalRead(c4) == HIGH){
      //travar code
    }
  }

  Serial.println(" ");
}

void setup (){
  Serial.begin(115200);

  //Pinos ligados aos pinos 1, 2, 3 e 4 do teclado - Linhas
  pinMode(l1, OUTPUT);
  pinMode(l2, OUTPUT);
  pinMode(l3, OUTPUT);
  pinMode(l4, OUTPUT);

  //Pinos ligados aos pinos 5, 6, 7 e 8 do teclado - Colunas
  pinMode(c1, INPUT);
  pinMode(c2, INPUT);
  pinMode(c3, INPUT);
  pinMode(c4, INPUT);

  Serial.begin(115200);
  Serial.println("Aguardando acionamento das teclas...");
}

void loop (){
  desligar();
  digitalWrite(l1, HIGH);
  pesquisar(1);

  delay(50);

  desligar();
  digitalWrite(l2, HIGH);
  pesquisar(2);

  delay(50);

  desligar();
  digitalWrite(l3, HIGH);
  pesquisar(3);

  delay(50);

  desligar();
  digitalWrite(l4, HIGH);
  pesquisar(4);

  delay(100);
}

/**********************************/

//usando a biblioteca keypad :D
/*//https://techtutorialsx.com/2017/03/18/esp8266-interfacing-with-a-4x4-matrix-keypad/ (modificado 08/12/2018)

#include <Arduino.h>
#include <Keypad.h>

const byte n_rows = 4;
const byte n_cols = 4;

char keys[n_rows][n_cols] = {
  {'1','2','3','A'},
  {'4','5','6','B'},
  {'7','8','9','C'},
  {'*','0','#','D'}
};

byte colPins[n_rows] = {D3, D2, D1, D0};
byte rowPins[n_cols] = {D7, D6, D5, D4};

Keypad myKeypad = Keypad( makeKeymap(keys), rowPins, colPins, n_rows, n_cols);

void setup(){
  Serial.begin(115200);
}

void loop(){
  char myKey = myKeypad.getKey();

  if (myKey != NULL){
    Serial.print("Key pressed: ");
    Serial.println(myKey);
  }
}
*/
